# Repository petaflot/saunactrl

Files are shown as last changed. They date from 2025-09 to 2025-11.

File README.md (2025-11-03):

Generally, a **finite state machine** that runs on ESP microcontrollers.

Control a sauna with ESP8266, PID (1-wire Dallas temperature sensors), web server.

Interface makes it easy to program temperature profiles (on another host, over
HTTP), so *sauna* can also be an oven, a drying rig, refrigeration unit, or any
other similar climate-controled device. Focus is on clean and versatile code.

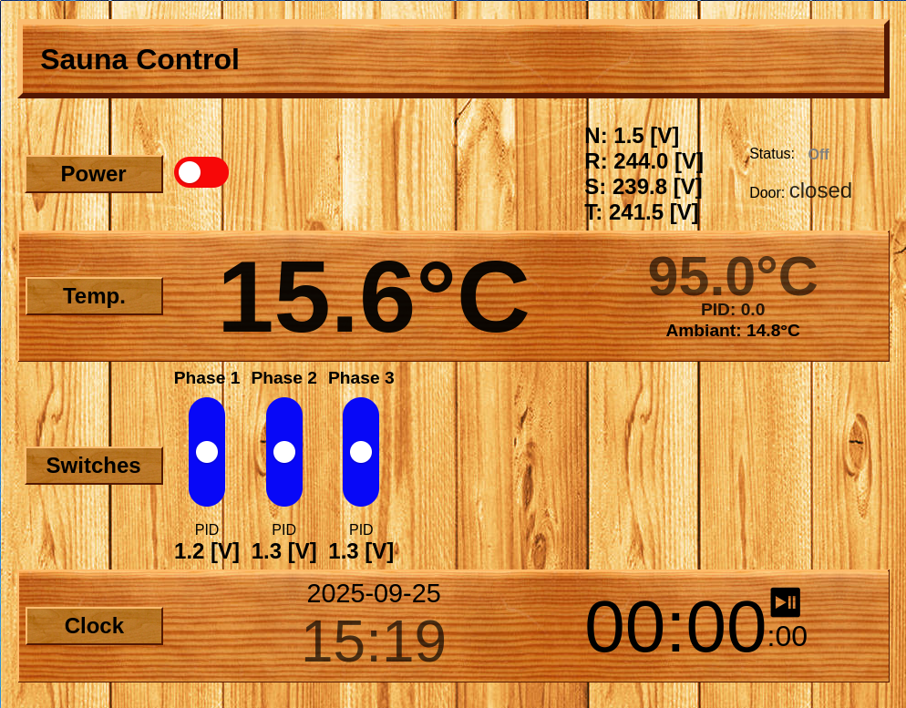
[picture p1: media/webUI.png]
status page


# Features

* PID-based temperature control
* remotely enable/disable device
* remotely set temperature target
* low-latency UI updates (websocket) ; works well with multiple clients
* CLI prototype (python) for easy scripting
* independant phase control, code mostly supports configurable number of outputs
* staged proportional heating (SSR on slow PWM) or (slower still) staged control of electromechanical relays
* door switch support and client-side timer (with auto-start)
* optional [PS-VM-RD](https://electro.nimag.net/PS-VM-RD/) integration (voltage measure)
* ESP starts in AP mode if SSID is not configured, or if connection to configured SSID fails after configured timeout

## TODO

In no particular order...

* HTTPS on ESP32
* RGB lighting (connect to WLED host?)
* ice bath
* Timing bell and deadman's switch
* Max power setting for controlled temperature slopes
* some sort of authentication mechanism
* HTML form to set parameters
* make HTML (and js and css) support configured number of relays
* temperature graph in HTML UI (host-side temperature history)
* TRIAC output
* PS-VM-RD temperature and relays
* bar-graph style power output for SSR and TRIAC widgets
* autocloud integration

A few more TODOs reside in the code ; just grep it.

# Safety note

It is advised to use a certified, external protection such as the [Danfoss KP85
(060L125666)](https://store.danfoss.com/us/en_US/Sensing-solutions/Switches/Temperature-switches/KP/Thermostat%2C-KP85/p/060L125666)
thermostat: trip point set slightly above the max operating temperature, **NO
SELF RESET / MANUAL RESET ONLY**.

In any case, the author does not endorse **ANY** responsibility in case of
malfunction, fire, injury or whatsoever : **YOU ARE ON YOUR OWN**, and **NEVER
LEAVE A POWERED DEVICE UNATTENDED**.

# Hardware Stuff

## Pin assignments:
This is valid for ESP8266 ; for more advanced features (ie. PS-VM-RD support, ESP32 is recommended)

```
ESP   label       PS-VM-RD
--------------------------
D0    WS2812_Din   -
D1    OneWire      - // temperature sensors
D2    RAON        7
D3    RELAY1       -
D4    DOOR_SW      -
D5    SCLK        15
D6    (MISO) SDO  14
D7    (MOSI) SDI  13
D8    (CS) LATCH  16
RX    RELAY2       -
TX    RELAY3       -
A0    AOUTA       12 // for PS-VM-RD
```

# Software Stuff

## Compile, upload and monitor

Copy `src/network.h.example` and save your changes in `src/network.h`. Check configuration options in `src/main.cpp`. Then:

```sh
pio run --target uploadfs
pio run --target upload
pio device monitor
```

## Remote operation

### Enable

`curl http://<ip>/enable`

### Disable

`curl http://<ip>/disable`

### Set temperature

`curl http://<ip>/set?target=<float temperature>`

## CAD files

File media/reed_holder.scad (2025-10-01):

use <scadlib/scadlib.scad>
include <scadlib/truefalse.scad>

minth = 2;
screwd = 3.5;
du = .01;
fn = 16;
more = 2;
cable_d = 4;

module cube_magnet_holder(l=5.15, width=3, offset=2, slide=8)
{
	difference()
	{
		union()
		{
			hull()
			{
				//%translate([0,-more,0]) prism(fn,[width*l+4*minth+2*(screwd+more), l+minth+2*more, minth], center=tff);
				translate([-width*l/2-2*minth,-more,0]) prism(fn,[l+minth+2*more, 2*(screwd+more)+slide, minth], center=tff);
				translate([ width*l/2+2*minth,-more,0]) prism(fn,[l+minth+2*more, 2*(screwd+more)+slide, minth], center=tff);
				translate([0,-offset,0]) prism(0,[width*l, l+minth+offset, minth], center=tff);
			}
			hull()
			{
				translate([0,-offset,0]) prism(0,[width*l-2*more, l+minth+offset+slide, minth], center=tff);
				translate([0,-offset,0]) prism(0,[l+2*minth, l+minth, l+2*minth], center=tff);
			}
		}
		union()
		{
			translate([0,-du-offset,minth]) prism(0,[l,l,l],center=tff);
			hull()
			{
				translate([-(width*l/2+minth+screwd/2),l/2+minth/2+slide,-du]) cylinder(d1=screwd,d2=screwd+2*minth,h=minth+2*du);
				translate([-(width*l/2+minth+screwd/2),l/2+minth/2,-du]) cylinder(d1=screwd,d2=screwd+2*minth,h=minth+2*du);
			}
			hull()
			{
				translate([ (width*l/2+minth+screwd/2),l/2+minth/2+slide,-du]) cylinder(d1=screwd,d2=screwd+2*minth,h=minth+2*du);
				translate([ (width*l/2+minth+screwd/2),l/2+minth/2,-du]) cylinder(d1=screwd,d2=screwd+2*minth,h=minth+2*du);
			}
		}
	}
}

/*
 * almost the same as cube_magnet_holder, but with more parameters (and has fixed position (no slides)
 */
module reed_holder(l=75, d=5.15, width=1.3, offset=5, wire_d=3, exit_left=true)
{
	difference()
	{
		union()
		{
			hull()
			{
				translate([0,-more,0]) prism(fn,[width*l+4*minth+2*(screwd+more), d+minth+2*more, minth], center=tff);
				translate([0,-offset,0]) prism(0,[width*l, d+minth+offset, minth], center=tff);
			}
			hull()
			{
				translate([0,-offset,0]) prism(0,[width*l-2*more, d+minth+offset, minth], center=tff);
				translate([0,-offset,0]) prism(0,[l+2*minth, d+minth, d+2*minth], center=tff);
			}
		}
		union()
		{
			translate([0,-du-offset,minth]) prism(0,[l,d,d],center=tff);
			translate([-(width*l/2+minth+screwd/2),d/2+minth/2,-du]) cylinder(d1=screwd,d2=screwd+2*minth,h=minth+2*du);
			translate([ (width*l/2+minth+screwd/2),d/2+minth/2,-du]) cylinder(d1=screwd,d2=screwd+2*minth,h=minth+2*du);
			// wire exit
			translate([(exit_left ? -l/2:l/2),-du-offset+d,minth+wire_d/2])
			rotate([0,(exit_left ? 90:-90),0]) cylinder(d=wire_d,h=l*width,$fn=8);
		}
	}
	// print supports (remove after)
	n = 2; // how many (per side! ATM always one in the middle)
	for (i=[-n:1:n])
	translate([(i==0?0:l/(2*(n+1))*i),-offset,minth]) prism(0,[1,.7,d],center=tff);
}

module cable_holder()
{
   width = 10;
   l = 8;
   intersection()
   {
   	prism(0,[3*width,l+2*width,cable_d+minth]);
   	difference()
   	{
   		union()
		{
			prism(fn,[width, width+l, minth]);
			translate([0,-l/2,0]) rotate([90,0,90]) prism(fn,[cable_d+2*minth,2*cable_d+2*minth,width],center=ttt);
		}
		union()
		{
			translate([ 0,l/2,-du]) cylinder(d1=screwd,d2=screwd+2*minth,h=minth+2*du);
			translate([0,-l/2,0]) rotate([90,0,90]) prism(fn,[cable_d,2*cable_d,2*width],center=ttt);
		}
   	}
   }
}

//translate([0,-10,0]) rotate([0,0,180])
*cube_magnet_holder();
*reed_holder(exit_left=false);

cable_holder();

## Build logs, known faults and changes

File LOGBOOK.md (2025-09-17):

# Sun Sep 14 17:43:48 CEST 2025

SSR du milieu leak bcp depuis ce matin (~165V en sortie quand ouvert), radiateur/support à 31.4°C maintenant mais bcp plus chaud ce matin (t_amb ~= 19°C). Courant mesuré: 5.2A à l'arrêt (erreur!) et 6.9A en marche.

J'ai constaté des trucs bizzares, les sorties qui ne réagissent pas pareil, l'interface web qui fonctionne ou pas malgré que les paramètres de SAMPLE_RATE_HZ soient les mêmes.. bizzare bizzare. 

Quelques minutes plus tard, par curiosité je monte sur le desktop pour tester: timeout dans l'interface, ping times très variables et parfois jusqu'à presque une seconde.. pas moyen d'avoir l'UI. sur le laptop (en bas près du sauna, wifi) ça fonctionne. je ferme l'onglet, ressaie sur le desktop... pareil. je descends chercher le laptop pour l'avoir à côté du desktop, et là miracle ça fonctionne pareil sur les 2 machines.

# Tue Sep 16 12:46:19 CEST 2025

SSR changé hier,, semblait leaker aussi (tension semble osciller entre 30 et 80 V) mais ce matin U à presque 0, donc semble OK au final.

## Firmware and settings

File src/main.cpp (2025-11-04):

// vim: et ts=2 number
/*
 * sauna control software (or more generally, climate control)
 *
 * date: 	09-2025
 * author:	JCZD
 */
#include <Arduino.h>
//#include <ArduinoJson.h>
#include <EEPROM.h>
#include <ESP8266WiFi.h>
#include <ESPAsyncTCP.h>
//#define ASYNC_TCP_DEBUG 1   // For ESP32
//#define DEBUG_ESP_ASYNC_TCP 1
#define DEBUG_ASYNC_HTTP_WEB_SERVER // For ESP8266
#include <ESPAsyncWebServer.h>
#include <OneWire.h>
#include <DallasTemperature.h>
#include <PID_v1.h>
#include <LittleFS.h>
#include <network.h>
#include "hmac.h"
#include "canon.h"
#include "json.h"
#include <ArduinoJson.h>

#define RELAY_OPEN HIGH
#define RELAY_CLOSED LOW

// for HMAC verification
const char *secret = "my_secret_seed";

// this will enable serial debugging output ; number is index of prefered relay in relayPins (MUST NOT be on RX or TX)
#define SINGLEPHASE_TESTMODE 0

// do we have a PS-VM-RD unit attached?
#define FEATURES_PSVMRD

// are we using slow electromechanical relays?
//#define ELECTROMECHANICAL
// should we use some time-window-based PWM (NOT for electromechanical relays!)
#define STAGED_SSRs
// do we have fast (cycle-precision with zero-passing detection) TRIAC phase control? TODO
//#define SMOOTH_TRIAC


#define TEMP_ABSMAX 125 // target temperature may NEVER be set above this point
#define TEMP_ERROR -127.0

const int EEPROM_SIZE = 32;
const int ADDR_SETPOINT = 0;
const int ADDR_RELAYMODES = 1;

#ifndef SINGLEPHASE_TESTMODE
constexpr size_t RELAY_COUNT = 3;
#else
constexpr size_t RELAY_COUNT = 1;
#endif

//#define WS2812_Din	D0
#define ONE_WIRE_BUS	D1      // GPIO for temperature sensors
//#define RAON		D2
#define RELAY1 		D3
#define	DOOR_SW		D4	// NOTE: when on D4, door MUST be open for flashing!!

#ifndef SINGLEPHASE_TESTMODE
// on TX/RX
#define RELAY2 		1
#define RELAY3 		3
#endif


#ifdef FEATURES_PSVMRD
#include <psvmrd.h>
#endif


OneWire oneWire(ONE_WIRE_BUS);
DallasTemperature sensors(&oneWire);
DeviceAddress sensor0, sensor1;

AsyncWebServer server(80);
AsyncWebSocket ws("/ws");

// PID setup
double Setpoint = 75.0, Input = 0, Output = 0, Ambiant = 0;

// Gains tuned for slow thermal response
double Kp = 5.0;   // stronger proportional action
double Ki = 2.;    // weaker integral to avoid windup
double Kd = 2.0;    // derivative helps damp oscillations

PID myPID(&Input, &Output, &Setpoint, Kp, Ki, Kd, DIRECT);

// Time-proportional control
#ifdef STAGED_SSRs
const unsigned long windowSize = 10000; // 10 seconds
unsigned long windowStartTime = 0;
#endif


// Relay control
bool enabled = false;
bool door_is_open;
unsigned long lastSend = 0;
#ifndef SINGLEPHASE_TESTMODE
const int relayPins[RELAY_COUNT] = { RELAY1, RELAY2, RELAY3 };
#else
const int relayPins[RELAY_COUNT] = { RELAY1 };
#endif
enum RelayModes { RELAY_OFF, RELAY_PID, RELAY_ON };
RelayModes relayModes[RELAY_COUNT] = {};
enum RelayStates { RELAY_IS_OFF, RELAY_IS_ON, SOMETHING_IS_BROKEN };
RelayStates relayStates[RELAY_COUNT] = {};  // TODO only use ifdef ELECTROMECHANICAL
RelayStates lastRelayStates[RELAY_COUNT] = {};

#ifdef ELECTROMECHANICAL
  #ifdef STAGED_SSRs
    "only one of ELECTROMECHANICAL, STAGED_SSRs or SMOOTH_TRIAC may be enabled"
  #else
    #ifdef SMOOTH_TRIAC
      "only one of ELECTROMECHANICAL, STAGED_SSRs or SMOOTH_TRIAC may be enabled"
    #endif
  #endif
#else
  unsigned long relayDutyCycles[RELAY_COUNT] = {};
  #ifdef STAGED_SSRs
    #ifdef SMOOTH_TRIAC
      "only one of ELECTROMECHANICAL, STAGED_SSRs or SMOOTH_TRIAC may be enabled"
    #endif
  #endif
#endif

#include <json.cpp>
JsonBuilder jb;


// Helper to strip "hmac" field from JSON and return the remaining JSON
bool strip_hmac_field(String &json, String &provided_hmacHex) {
    int hmacPos = json.indexOf("\"hmac:");
    if (hmacPos < 0) return false;  // no hmac field found

    // Extract HMAC value
    provided_hmacHex = json.substring(hmacPos + 6, hmacPos + 70);
    //Serial.print("provided_hmacHex: ");
    //Serial.println(provided_hmacHex);

    json.remove(hmacPos-1, 72);
    return true;
}

/*
void saveValueToEEPROM(int save_where, double val) {
  EEPROM.put(save_where, val);
  EEPROM.commit();
}
*/

void loadSetpoint() {
  double val;
  EEPROM.get(ADDR_SETPOINT, val);
  if (!isnan(val) && val > 0 && val < TEMP_ABSMAX && val > TEMP_ERROR) {
    Setpoint = val;
  }
}

void loadRelayModes() {
  double val;
  EEPROM.get(ADDR_RELAYMODES, val);
  // TODO
}

void process_validated_request(AsyncWebServerRequest *request)
{
    if (request->hasParam("target")) {
      String val = request->getParam("target")->value();
      double newTarget = val.toFloat();
      if (newTarget > 0 && newTarget < TEMP_ABSMAX) {
        Setpoint = newTarget;
	      jb.addValue( "target", Setpoint);
        ws.textAll(jb.finish());
        request->send(200, "text/plain", "Target set to " + String(Setpoint,1));
        Serial.println("New Setpoint: " + String(Setpoint));
      } else {
        request->send(400, "text/plain", "Invalid value");
      }
      if (request->hasParam("save")) EEPROM.put(ADDR_SETPOINT, Setpoint);
    }
    if (request->hasParam("relay")) {
      String msg = request->getParam("relay")->value(); // <-- declare msg here

      size_t r = msg.substring(6, 7).toInt() - 1;
      String mode = msg.substring(8);

      if (r >= 0 && r < RELAY_COUNT) {
        if (mode == "on") relayModes[r] = RELAY_ON;
        else if (mode == "off") relayModes[r] = RELAY_OFF;
        else if (mode == "pid") relayModes[r] = RELAY_PID;

        if (request->hasParam("save")) EEPROM.put(ADDR_RELAYMODES, relayModes);

        jb.addValue("relayModes", relayModes);
        ws.textAll(jb.finish());
      }
    }
    if (request->hasParam("save")) EEPROM.commit();
}


void handleWebSocketMessage(void *arg, uint8_t *data, size_t len, AsyncWebSocketClient *client) {
  AwsFrameInfo *info = (AwsFrameInfo*)arg;
  if (info->final && info->index == 0 && info->len == len && info->opcode == WS_TEXT) {
    String msg;
    for (size_t i = 0; i < len; i++) {
      msg += (char)data[i];
    }
#ifdef SINGLEPHASE_TESTMODE
    Serial.println("Received WebSocket message: " + msg);

    // Step 1 & 2: Extract HMAC and remove it
    String provided_hmacHex;
    if (!strip_hmac_field(msg, provided_hmacHex)) { return; }

    //Serial.println("Extracted HMAC: " + provided_hmacHex);
    //Serial.println("JSON without HMAC: " + msg);

    // Step 3: Canonicalize and recompute new HMAC
    /*
    KV kvs[MAX_KV];
    String dummy;
    size_t n = parseJsonToKVs(msg, kvs, MAX_KV, dummy);
    sortKVs(kvs, n);
    String canonical = buildCanonical(kvs, n);
    */

    String recomputed_hmac = compute_hmac_hex(secret, msg);
    //Serial.println("Recomputed HMAC: " + recomputed_hmac);

    // Step 4: Compare
    if (!hex_equals_ci(provided_hmacHex, recomputed_hmac)) {
      Serial.println("❌ HMAC verification FAILED");
    } else {
      //Serial.println("✅ HMAC verified successfully");
      return;
    }

    StaticJsonDocument<256> doc;
    if (deserializeJson(doc, msg)) {
        Serial.println("❌ JSON parse error");
        return;
    }

    MockRequest request;
    request.client = client;
    for (JsonPair kv : doc.as<JsonObject>()) {
        request.params.push_back({ kv.key().c_str(), kv.value().as<String>() });
    }

    // Call existing parser for WS message
    process_validated_request(reinterpret_cast<AsyncWebServerRequest*>(&request));

#endif
    // broadcast value changes
    if (msg == "enable") {
      enabled = true;
      jb.addValue("enabled", true);
      ws.textAll(jb.finish());

    } else if (msg == "disable") {
      enabled = false;
      jb.addValue("enabled", false);
      jb.addValue("pid", 0); // kinda dirty hack for code simplicity
      ws.textAll(jb.finish());

    } else if (msg.startsWith("target:")) {
      Setpoint = msg.substring(7).toFloat();
      jb.addValue("target", Setpoint);
      ws.textAll(jb.finish());

    } else if (msg.startsWith("relay:")) {
      size_t r = msg.substring(6,7).toInt() - 1; // relay index 0..2
      String mode = msg.substring(8);
      if (r >= 0 && r < RELAY_COUNT) {
        if (mode == "on") relayModes[r] = RELAY_ON;
        else if (mode == "off") relayModes[r] = RELAY_OFF;
        else if (mode == "pid") relayModes[r] = RELAY_PID;
      }
      jb.addValue("relayModes", relayModes);
      ws.textAll(jb.finish());

    } else if (msg == "enabled") {
      jb.addValue("enabled:", enabled ? "true" : "false");
      client->text(jb.finish());

    } else if (msg == "ambiant") {
      jb.addValue("ambiant", Ambiant);
      client->text(jb.finish());

    } else if (msg == "temp") {
      jb.addValue("temp", Input);
      client->text(jb.finish());

    } else if (msg == "door") {
      jb.addValue("door", door_is_open ? "open" : "closed");
      client->text(jb.finish());

    } else if (msg == "relays") {
      jb.addValue("relayModes", relayModes);
#ifdef STAGED_SSRs
      jb.addValue("relayDutyCycles", relayDutyCycles);
#else
      jb.addValue("relayStates", relayStates);
#endif
      client->text(jb.finish());

#ifdef FEATURES_PSVMRD
    } else if (msg == "voltages") {
      getVoltages(volts);
      jb.addValue("voltages", volts);
      client->text(jb.finish());
#endif
    }
    jb.clear();
  }
}

void onEvent(AsyncWebSocket *server, AsyncWebSocketClient *client, AwsEventType type,
             void *arg, uint8_t *data, size_t len) {
  if (type == WS_EVT_CONNECT) {
    IPAddress ip = client->remoteIP();
//#ifdef SINGLEPHASE_TESTMODE
    //Serial.printf("Client connected: #%u from %s\n", client->id(), ip.toString().c_str());
//#endif
    jb.addValue("client", ip.toString().c_str());
  } else if (type == WS_EVT_DATA) {
    handleWebSocketMessage(arg, data, len, client);
  }
}

void setup() {


  EEPROM.begin(EEPROM_SIZE);

  pinMode(DOOR_SW, INPUT_PULLUP);
  std::fill_n(relayModes, RELAY_COUNT, RELAY_PID);
#ifdef SINGLEPHASE_TESTMODE
  Serial.begin(115200);
  delay(500);
  std::fill_n(relayStates, RELAY_COUNT, SOMETHING_IS_BROKEN);
  relayStates[SINGLEPHASE_TESTMODE] = RELAY_IS_OFF;
  pinMode(relayPins[SINGLEPHASE_TESTMODE], OUTPUT);
  digitalWrite(relayPins[SINGLEPHASE_TESTMODE], RELAY_OPEN);
#else
  std::fill_n(relayStates, RELAY_COUNT, RELAY_IS_OFF);
  for (size_t i = 0; i < RELAY_COUNT; i++) {
    pinMode(relayPins[i], OUTPUT);
    digitalWrite(relayPins[i], RELAY_OPEN);
  }
#endif
  memcpy(lastRelayStates, relayStates, sizeof(relayStates));

  // load saved parameters from EEPROM
  loadSetpoint();
  loadRelayModes();

  /*
  Serial.println("HMAC verification demo");

  // Received JSON string (includes HMAC)
  String incoming = "{\"target\":75,\"enabled\":true,\"hmac\":\"b1af1bf40a497e3724dbbcf2481ab91ff1ae485d904fc3713cf284db4bd8c4c7\"}";

  // Step 1 & 2: Extract HMAC and remove it
  String received_hmac;
  String json_no_hmac = strip_hmac_field(incoming, received_hmac);

  Serial.println("Received JSON: " + incoming);
  Serial.println("JSON without HMAC: " + json_no_hmac);

  // Step 3: Canonicalize and recompute new HMAC
  KV kvs[MAX_KV];
  String dummy;
  size_t n = parseJsonToKVs(json_no_hmac, kvs, MAX_KV, dummy);
  sortKVs(kvs, n);
  String canonical = buildCanonical(kvs, n);

  String recomputed_hmac = compute_hmac_hex(secret, canonical);

  Serial.println("Canonical: " + canonical);
  Serial.println("Extracted HMAC:  " + received_hmac);
  Serial.println("Recomputed HMAC: " + recomputed_hmac);

  // Step 4: Compare
  if (hex_equals_ci(received_hmac, recomputed_hmac)) {
    Serial.println("✅ HMAC verified successfully");
  } else {
    Serial.println("❌ HMAC verification FAILED");
  }
*/

  sensors.begin();
  if (!sensors.getAddress(sensor0, 0)) {
#ifdef SINGLEPHASE_TESTMODE
    Serial.println("No temperature sensor found");
#endif
  } else {
#ifdef SINGLEPHASE_TESTMODE
    Serial.print("Sensor 0 address: ");
    for (uint8_t i = 0; i < 8; i++) {
      Serial.printf("%02X", sensor0[i]);
    }
    Serial.println();
#endif
  }

  if (!sensors.getAddress(sensor1, 1)) {
#ifdef SINGLEPHASE_TESTMODE
    Serial.println("No second temperature sensor found");
#endif
    // TODO dangerous, do not run!
    //while (1) delay(10000);

  } else {
#ifdef SINGLEPHASE_TESTMODE
    Serial.print("Sensor 1 address: ");
    for (uint8_t i = 0; i < 8; i++) {
      Serial.printf("%02X", sensor1[i]);
    }
    Serial.println();
#endif
  }

  if (!LittleFS.begin()) {
#ifdef SINGLEPHASE_TESTMODE
    Serial.println("Failed to mount LittleFS");
#endif
    return;
  } else {
#ifdef SINGLEPHASE_TESTMODE
    Serial.println("Listing files in LittleFS:");
    Dir dir = LittleFS.openDir("/");
    while (dir.next()) {
      Serial.print("  ");
      Serial.print(dir.fileName());
      Serial.print(" (");
      Serial.print(dir.fileSize());
      Serial.println(" bytes)");
    }
#endif
  }

  /*if (!LittleFS.exists("/index.html")) {
    Serial.println("index.html not found in LittleFS!");
  } else {
    Serial.println("index.html found in LittleFS");
  }*/

  // Configure STA mode
  if (!WiFi.config(local_IP, gateway, subnet, dns)) {
#ifdef SINGLEPHASE_TESTMODE
    Serial.println("STA failed to configure (invalid static IP config)");
#endif
  }
  
  // Start connection (with or without BSSID)
#ifdef ssid
#ifdef bssid
  WiFi.begin(ssid, password, 0, bssid);
#else
  WiFi.begin(ssid, password);
#endif
  
#ifdef SINGLEPHASE_TESTMODE
  Serial.print("Connecting to WiFi");
#endif
  
  unsigned long startAttemptTime = millis();
  const unsigned long connectTimeout = 7'000;  // 10 seconds timeout
  
  // Wait for connection or timeout
  while (WiFi.status() != WL_CONNECTED && millis() - startAttemptTime < connectTimeout) {
    delay(500);
#ifdef SINGLEPHASE_TESTMODE
    Serial.print(".");
#endif
  }
#endif
  
  // If still not connected or BSSID not configured → fallback to AP mode
  if (WiFi.status() != WL_CONNECTED
#ifndef ssid
      || true  // No BSSID configured, force AP mode
#endif
  ) {
#ifdef SINGLEPHASE_TESTMODE
    Serial.println("\nConnection failed or no BSSID configured, starting in AP mode");
#endif
    WiFi.disconnect(true);
    delay(500);
  
    WiFi.mode(WIFI_AP);
    WiFi.softAPConfig(ap_local_IP, ap_gateway, ap_subnet);
    WiFi.softAP(ap_ssid, ap_passphrase);
  
#ifdef SINGLEPHASE_TESTMODE
    Serial.printf("SSID:          %s\n", ap_ssid);
    Serial.printf("Passphrase:    %s\n", ap_passphrase);
    Serial.print( "AP IP address: ");
    Serial.println(WiFi.softAPIP());
#endif
  } else {
#ifdef SINGLEPHASE_TESTMODE
    Serial.println("\nWiFi connected");
    Serial.print("IP address: ");
    Serial.println(WiFi.localIP());
    Serial.print("Device MAC address: ");
    Serial.println(WiFi.macAddress());
    Serial.print("Connected to BSSID: ");
    Serial.println(WiFi.BSSIDstr());
#endif
  }


  myPID.SetMode(AUTOMATIC);
  myPID.SetOutputLimits(0, 1); // 3 relays, but non-uniform power outputs

  server.serveStatic("/", LittleFS, "/").setDefaultFile("index.html");
  /*
  server.on("/", HTTP_GET, [](AsyncWebServerRequest *request){
    Serial.println("Request received for /");
    try {
      // Your logic here
      request->send(200, "text/plain", "OK");
    } catch (...) {
      Serial.println("Handler crashed!");
      request->send(500, "text/plain", "Internal Server Error");
    }
  });
  */

  ws.onEvent(onEvent);
  server.addHandler(&ws);

  server.onNotFound([](AsyncWebServerRequest *request){
    //if(LittleFS.exists("/404.html")){
    //  request->send(LittleFS, "/404.html", "text/html", false); // TODO write this page (and make it pretty)
    //} else {
      request->send(404, "text/plain", "404: Not Found");
    //}
  });

  server.on("/enable", HTTP_GET, [](AsyncWebServerRequest *request){
    enabled = true;
    request->send(200, "text/plain", "Sauna enabled");
    jb.addValue("enabled", true);
    ws.textAll(jb.finish());
  });
  
  server.on("/disable", HTTP_GET, [](AsyncWebServerRequest *request){
    enabled = false;
    request->send(200, "text/plain", "Sauna disabled");
    jb.addValue("enabled", false);
    ws.textAll(jb.finish());
  });
  
  server.on("/status.json", HTTP_GET, [](AsyncWebServerRequest *request){
    String msg = "{";
    msg += "\n\t\"temp\":" + String(Input, 2);
    msg += ",\n\t\"target\":" + String(Setpoint, 2);
    msg += ",\n\t\"ambiant\":" + String(Ambiant, 2);
    msg += ",\n\t\"enabled\":" + String(enabled ? "true" : "false");
    msg += ",\n\t\"door\":" + String(door_is_open ? "\"open\"" : "\"closed\"");
  
    // relayModes
    msg += ",\n\t\"relayModes\":[";
    for (size_t i = 0; i < RELAY_COUNT; i++) {
      msg += String((int)relayModes[i]);
      if (i < RELAY_COUNT - 1) msg += ",";
    }
    msg += "]";
  
#ifdef ELECTROMECHANICAL
    // relayStates
    msg += ",\n\t\"relayStates\":[";
    for (size_t i = 0; i < RELAY_COUNT; i++) {
      msg += relayStates[i] ? "1" : "0";
      if (i < RELAY_COUNT - 1) msg += ",";
    }
    msg += "]";
#else
    msg += ",\n\t\"relayDutyCycles\":[";
    for (size_t i = 0; i < RELAY_COUNT; i++) {
      msg += String(relayDutyCycles[i], 3);
      if (i < RELAY_COUNT - 1) msg += ",";
    }
    msg += "]";
#endif
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
void loop() {
  if (door_is_open != digitalRead(DOOR_SW)){
    door_is_open = digitalRead(DOOR_SW);
    jb.addValue("door", door_is_open ? "open" : "closed");
  }

  sensors.requestTemperatures();
  Input = sensors.getTempC(sensor0);
  Ambiant = sensors.getTempC(sensor1);

#ifdef STAGED_SSRs
  for (size_t i = 0; i < RELAY_COUNT; i++) {
    relayDutyCycles[i] = 0;
  }
#endif

  if (enabled && !door_is_open && Input != DEVICE_DISCONNECTED_C) {
    myPID.Compute();
#ifdef SINGLEPHASE_TESTMODE
    Serial.printf("Temp: %.2f °C, Target: %.2f °C, PID Output: %.2f\n", Input, Setpoint, Output);
#endif

#ifndef STAGED_SSRs
    // Apply relay states
    // TODO dynamic based on RELAY_COUNT and a (new) relayWatts list
#ifndef SINGLEPHASE_TESTMODE
    for (size_t i = 0; i < RELAY_COUNT; i++) {
	    digitalWrite(relayPins[i], (relayModes[i] == RELAY_ON) ? RELAY_CLOSED :
		    (relayModes[i] == RELAY_PID && Output >= i ? RELAY_CLOSED : RELAY_OPEN));
    }
#else
	  digitalWrite(relayPins[SINGLEPHASE_TESTMODE], (relayModes[SINGLEPHASE_TESTMODE] == RELAY_ON) ? RELAY_CLOSED :
		  (relayModes[SINGLEPHASE_TESTMODE] == RELAY_PID && Output >= 1 ? RELAY_CLOSED : RELAY_OPEN));
#endif
    if (memcmp(relayStates, lastRelayStates, sizeof(relayStates)) != 0) {
      memcpy(lastRelayStates, relayStates, sizeof(relayStates));
      jb.addValue("relayStates", relayStates);
    }

#else
    //Serial.println("#def STAGED_SSRs");
    unsigned long now = millis();
    if (now - windowStartTime > windowSize) {
      windowStartTime = now; // reset window
    }

    // Stage SSRs ; NOTE: this is hardcoded for relative power levels [1,2,1]
    // TODO dynamic based on RELAY_COUNT and a (new) relayWatts list
    if (Output <= .25) {
      // Stage 1: SSR1 PWM only
      relayDutyCycles[0] = 4*Output;
    } else if (Output <= .75) {
      // Stage 2: SSR1 full, SSR2 PWM
      relayDutyCycles[0] = 1.;
#ifndef SINGLEPHASE_TESTMODE
      relayDutyCycles[1] = 2*(Output-.25);
#endif
    } else {
      // Stage 3: SSR1 + SSR2 full, SSR3 PWM
      relayDutyCycles[0] = 1.;
#ifndef SINGLEPHASE_TESTMODE
      relayDutyCycles[1] = 1.;
      relayDutyCycles[2] = 4*(Output-.75);
#endif
    }

    // Apply relay states
#ifndef SINGLEPHASE_TESTMODE
    for (size_t i = 0; i < RELAY_COUNT; i++) {
	    digitalWrite(relayPins[i], (relayModes[i] == RELAY_ON) ? RELAY_CLOSED :
		    (relayModes[i] == RELAY_PID && (now - windowStartTime) < relayDutyCycles[i]*windowSize ? RELAY_CLOSED : RELAY_OPEN));
    }
#else
	  digitalWrite(relayPins[SINGLEPHASE_TESTMODE], (relayModes[SINGLEPHASE_TESTMODE] == RELAY_ON) ? RELAY_CLOSED :
		  (relayModes[SINGLEPHASE_TESTMODE] == RELAY_PID && (now - windowStartTime) < relayDutyCycles[SINGLEPHASE_TESTMODE]*windowSize ? RELAY_CLOSED : RELAY_OPEN));
#endif
#endif

  } else {
#ifdef SINGLEPHASE_TESTMODE
    if (Input == DEVICE_DISCONNECTED_C) {
      //Serial.println("Sensor disconnected!"); TODO remove
    }
#endif
    Output = 0;
    for (size_t i = 0; i < RELAY_COUNT; i++) {
      digitalWrite(relayPins[i], RELAY_OPEN);
    }
  }

  if (millis() - lastSend > 5000) {
    if (enabled) jb.addValue("pid", Output);
    jb.addValue("temp", Input);
    jb.addValue("ambiant", Ambiant);
#ifdef STAGED_SSRs
    jb.addValue("relayDutyCycles", relayDutyCycles);
#endif

#ifdef FEATURES_PSVMRD
    getVoltages(volts);
    jb.addValue("voltages", volts);
#endif // FEATURES_PSVMRD
    lastSend = millis();
  }

  if (jb.hasValues()){
    ws.textAll(jb.finish());
    jb.clear();
  }

  delay(500);
}

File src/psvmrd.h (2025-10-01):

#include <hc_ad_mux.h>
#include <Ticker.h>

#define	SCLK		D5	// 74HCT595
//#define 	SDO		D6
#define	SDI		D7	// 74HCT595
#define	LATCH		D8	// 74HCT595
#define AOUTA		A0


// ADC calibration
const float ADC_VOLTAGE_REF = 1.0f;   // V (ESP8266 ADC range)
const int ADC_MAX = 1023;             // analogRead max (0..1023)
// TODO move this to another file
const float calibrationMultiplier = 875.0f; // approx, may need refining and per-device (and per-channel!) tuning

// Setup MUX1 (bits 0–2) and MUX2 (bits 3–5)
HC4051 mux1(0, LATCH, SCLK, SDI);
HC4051 mux2(1, LATCH, SCLK, SDI);
// System: MUX2 feeds into MUX1 channel 4
MUXSystem muxSys(AOUTA, mux1, mux2, 4);

// Sampling config
/* if sample rate is too high, WiFi starves and watchdog resets device!
 * 250 OK, 500 NOK, 330 OK, 400 starts choking, 350 already chokes
 * then fails at 250.. irregular ping times, I suppose two cores would be better!
 * works so-so, definitely favor two cores there!
 */
const int SAMPLE_RATE_HZ = 250;
const int BUFFER_SIZE = 100;

// TODO move this to another file
constexpr int NUM_CHANNELS = 7;  // up to 16 channels (8 mux1 + 8 mux2)
int adcChannels[NUM_CHANNELS] = {0, 1, 2, 3, 8, 9, 10};  // mux channel numbers to read

struct ChannelBuffer {
  int samples[BUFFER_SIZE];   // big buffer, lives in DRAM
  volatile uint16_t head;     // index, volatile because ISR writes it
};
// One buffer per channel, allocated globally (not on stack)
ChannelBuffer chanBuf[NUM_CHANNELS];

Ticker sampler;
int currentChannel = 0;

// ---- Sampling ISR ----
void sampleADC() {
  int raw;
  if (adcChannels[currentChannel] >= 8) {
    raw = muxSys.readMux2(adcChannels[currentChannel]-8);
  } else {
    raw = muxSys.readMux1(adcChannels[currentChannel]);
  }

  ChannelBuffer &buf = chanBuf[currentChannel];
  buf.samples[buf.head] = raw;
  buf.head = (buf.head + 1) % BUFFER_SIZE;

  if (currentChannel == (NUM_CHANNELS-1)){
    currentChannel = 0;
  } else {
    currentChannel++;
  }
}

// ---- Compute RMS on demand ----
float computeRMS(int chan) {
  noInterrupts();
  ChannelBuffer &buf = chanBuf[chan];
  interrupts();

  double sum = 0, sumSq = 0;
  for (int i = 0; i < BUFFER_SIZE; i++) {
    int v = buf.samples[i];
    sum += v;
    sumSq += (double)v * v;
  }

  double mean = sum / BUFFER_SIZE;
  double variance = (sumSq / BUFFER_SIZE) - (mean * mean);
  if (variance < 0) variance = 0;

  double rmsRaw = sqrt(variance);
  float voltsRMS = rmsRaw * (ADC_VOLTAGE_REF / ADC_MAX);
  return voltsRMS * calibrationMultiplier;
}

void getVoltages(float *out) {
    noInterrupts();
    for (size_t i = 0; i < NUM_CHANNELS; i++) {
        out[i] = computeRMS(i);
    }
    interrupts();
}
float volts[NUM_CHANNELS];

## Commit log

2025-09-07 improved status switch (status expires)
    with client-side watchdog
2025-09-08 relay states display (I) vs. ( )
    there may be a bug.. because the relay states change in slow sequence
    when PID is effective
    [main.cpp]
2025-09-10 fixed knobs position, improved layout (temp)
    [main.cpp]
2025-09-11 improved visuals, timer, better icon
2025-09-11 pretty background, improved timer
2025-09-12 ambiant temperature, timer fixes
    [main.cpp]
2025-09-18 reactivity update!!
    also improved bandwidth usage
    changes of values like relayStates, relayModes, doorStatus are pushed to
    clients immediately
2025-09-19 improved client and protocol ; fixed status.json bug
    [main.cpp]
2025-09-26 window-based slow PWM for SSR
    HTML UI does not report it yet!
2025-09-26 prototype implementation
2025-09-26 cleaned voltage measure
2025-10-01 staged SSR window-based control
    reporting of state in web UI is not operational
2025-10-01 improved status.json and README
    [reed_holder.scad]
2025-10-01 meeh oops (errata) ; PS-VM-RD moved out of main.cpp
    [main.cpp, psvmrd.h]
2025-11-03 ESP32 schematic
    [ESP32.kicad_pcb, ESP32.kicad_sch]
